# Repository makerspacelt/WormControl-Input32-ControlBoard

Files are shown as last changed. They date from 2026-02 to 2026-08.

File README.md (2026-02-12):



---
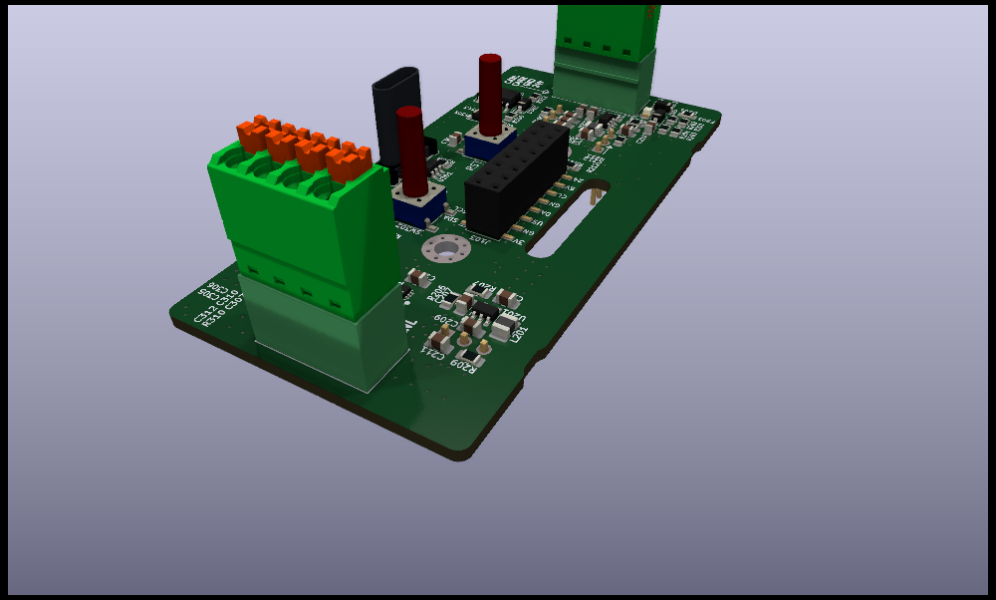
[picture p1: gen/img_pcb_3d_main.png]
PCB 3d main


WormControl Inputs Control board

NOTE: This is only a prototype now, so things might not work and everything might change 

Basic target features:

* Compatibility with esphome and Home Assistant

Dev NOTE: before commit, run `./kibot.sh` to regenerate documentation, bom, gerbers and other assets.

* [schematics.pdf](gen/schematics.pdf)
* [pcb.pdf with dimensions](gen/pcb.pdf)
* [ibom.html](gen/single/ibom.html)

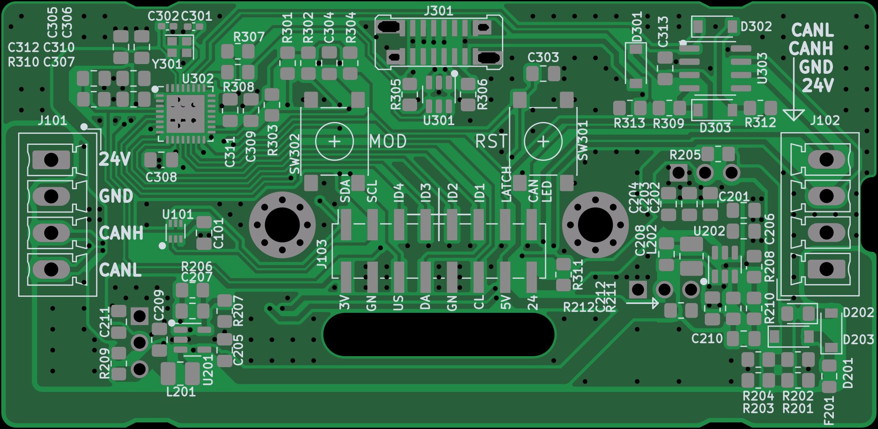
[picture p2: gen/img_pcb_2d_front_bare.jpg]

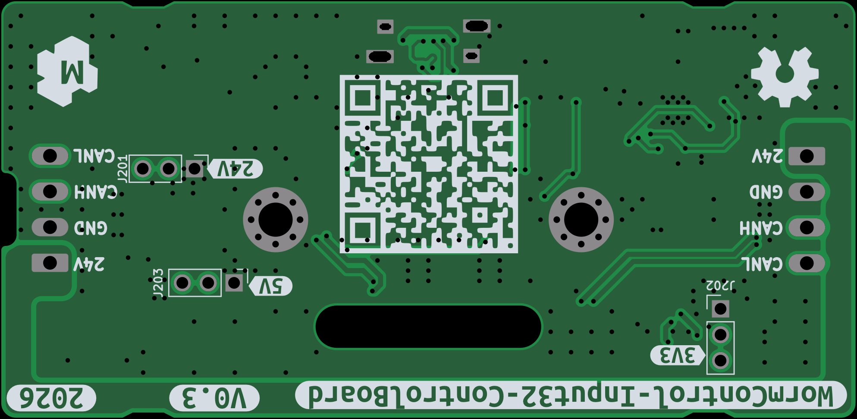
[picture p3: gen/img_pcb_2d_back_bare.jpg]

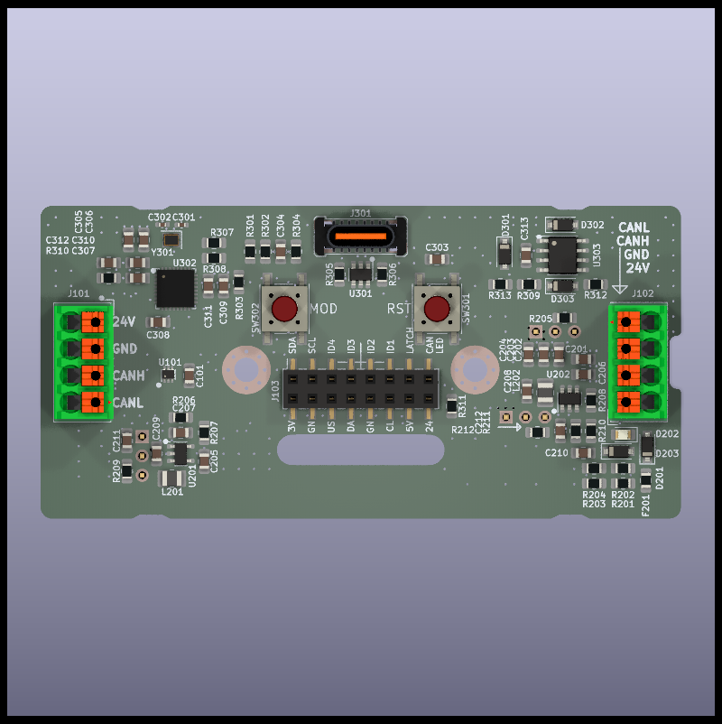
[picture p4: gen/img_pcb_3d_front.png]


---

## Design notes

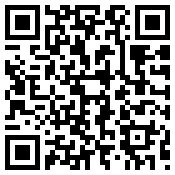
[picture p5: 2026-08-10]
gen/qr_link.png

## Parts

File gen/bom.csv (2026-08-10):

Row | Description | Part | References | Value | Footprint | Quantity Per PCB | Status | Datasheet | lcsc# | jlc-part-type
1 | Heatsink | Heatsink | BOM101,BOM102 | 1x4 screw plug |  | 2 |  | https://www.lcsc.com/datasheet/lcsc_datasheet_2309070925_DEGSON-15EDGKN-3-5-04P-14-00A-H_C7603442.pdf | C7603442 | E
2 | Unpolarized capacitor | C | C301,C302 | 10p | C_0402_1005Metric_Pad0.74x0.62mm_HandSolder | 2 |  | ~ | C32949 | B
3 | Unpolarized capacitor | C | C207,C210 | 100p | C_0805_2012Metric_Pad1.18x1.45mm_HandSolder | 2 |  | https://www.lcsc.com/datasheet/lcsc_datasheet_2304140030_Samsung-Electro-Mechanics-CL21C101JBANNNC_C1790.pdf | C1790 | B
4 | Unpolarized capacitor | C | C101,C206,C208,C303,C304,C307,C308,C309,C310,C311,C312,C313 | 100n | C_0805_2012Metric_Pad1.18x1.45mm_HandSolder | 12 |  | https://www.lcsc.com/datasheet/lcsc_datasheet_2304140030_Samsung-Electro-Mechanics-CL21B104KCFNNNE_C28233.pdf | C28233 | B
5 | Unpolarized capacitor | C | C306 | 1u | C_0805_2012Metric_Pad1.18x1.45mm_HandSolder | 1 |  | https://www.lcsc.com/datasheet/lcsc_datasheet_2304140030_Samsung-Electro-Mechanics-CL21B105KBFNNNE_C28323.pdf | C28323 | B
6 | Unpolarized capacitor | C | C201,C202,C203,C204,C212 | 10u/50v | C_0805_2012Metric_Pad1.18x1.45mm_HandSolder | 5 |  | https://www.lcsc.com/datasheet/lcsc_datasheet_2411041759_Murata-Electronics-GRM21BR61H106KE43L_C440198.pdf | C440198 | B
7 | Unpolarized capacitor | C | C205,C305 | 22u/25v | C_0805_2012Metric_Pad1.18x1.45mm_HandSolder | 2 |  | https://www.lcsc.com/datasheet/lcsc_datasheet_2304140030_Samsung-Electro-Mechanics-CL21A226MAQNNNE_C45783.pdf | C45783 | B
8 | Unpolarized capacitor | C | C209,C211 | 47u/6V3 | C_0805_2012Metric_Pad1.18x1.45mm_HandSolder | 2 |  | https://www.lcsc.com/datasheet/C16780.pdf | C16780 | B
9 | Schottky diode | D_Schottky | D201,D203,D301,D302,D303 | B5819W | D_SOD-123 | 5 |  | https://www.lcsc.com/datasheet/lcsc_datasheet_2304140030_Jiangsu-Changjing-Electronics-Technology-Co---Ltd--B5819W-SL_C8598.pdf | C8598 | B
10 | Light emitting diode | LED | D202 | BLUE | LED_0805_2012Metric_Pad1.15x1.40mm_HandSolder | 1 |  | https://www.lcsc.com/datasheet/C2297.pdf | C2297 | B
11 | Resettable fuse, polymeric positive temperature coefficient | Polyfuse | F201 | 250mA | Fuse_0805_2012Metric_Pad1.15x1.40mm_HandSolder | 1 |  | https://wmsc.lcsc.com/wmsc/upload/file/pdf/v2/lcsc/2404081622_BHFUSE-BSMD0805-025-33V_C22378353.pdf | C22378353 | E
12 | Generic connector, single row, 01x03, script generated (kicad-library-utils/schlib/autogen/connector/) | Conn_01x03 | J201,J202,J203 | 24V | PinHeader_1x03_P2.54mm_Vertical | 3 |  | ~ |  | -
13 | Generic screw terminal, single row, 01x04, script generated (kicad-library-utils/schlib/autogen/connector/) | Screw_Terminal_01x04 | J101,J102 | BUS | PhoenixContact_MCV_1,5_4-G-3.5_1x04_P3.50mm_Vertical | 2 |  | https://www.lcsc.com/datasheet/lcsc_datasheet_2304140030_Ningbo-Xinlaiya-Elec--XY2500V-F-3-5-4P_C880556.pdf | C880556 | E
14 | Generic connector, single row, 01x16, script generated (kicad-library-utils/schlib/autogen/connector/) | Conn_01x16 | J103 | Back | PinSocket_2x08_P2.54mm_Vertical_SMD | 1 |  | https://wmsc.lcsc.com/wmsc/upload/file/pdf/v2/lcsc/2306091018_HCTL-PM254-2-08-S-8-5_C3975153.pdf | C3975153 | E
15 | USB 2.0-only Type-C Receptacle connector | USB_C_Receptacle_USB2.0 | J301 | USB_C_Receptacle_USB2.0 | USB_C_Receptacle_G-Switch_GT-USB-7082G | 1 |  | https://www.lcsc.com/datasheet/lcsc_datasheet_2405271642_G-Switch-GT-USB-7082G_C22383836.pdf | C22383836 | E
16 | Inductor | L | L201,L202 | 3.3uH | L_1008_2520Metric_Pad1.43x2.20mm_HandSolder | 2 |  | https://www.lcsc.com/datasheet/C5832373.pdf | C5832373 | E
17 | Resistor | R | R205,R209,R212 | 0R1 | R_0805_2012Metric_Pad1.20x1.40mm_HandSolder | 3 |  | https://www.lcsc.com/datasheet/lcsc_datasheet_2304140030_UNI-ROYAL-Uniroyal-Elec-0805W8F100LT5E_C127687.pdf | C127687 | E
18 | Resistor | R | R307,R308 | 22R | R_0805_2012Metric_Pad1.20x1.40mm_HandSolder | 2 |  | ~ | C17561 | B
19 | Resistor | R | R309 | 1k5 | R_0805_2012Metric_Pad1.20x1.40mm_HandSolder | 1 |  | ~ | C4310 | B
20 | Resistor | R | R313 | 3k | R_0805_2012Metric_Pad1.20x1.40mm_HandSolder | 1 |  | ~ | C17661 | B
21 | Resistor | R | R201,R202,R203,R204,R301,R302,R303,R304,R305,R306,R310,R312 | 4k7 | R_0805_2012Metric_Pad1.20x1.40mm_HandSolder | 12 |  | ~ | C17673 | B
22 | Resistor | R | R207,R208,R210 | 10k | R_0805_2012Metric_Pad1.20x1.40mm_HandSolder | 3 |  | ~ | C17414 | B
23 | Resistor | R | R206 | 47k | R_0805_2012Metric_Pad1.20x1.40mm_HandSolder | 1 |  | ~ | C17713 | B
24 | Resistor | R | R211,R311 | 150k | R_0805_2012Metric_Pad1.20x1.40mm_HandSolder | 2 |  | ~ | C17470 | B
25 | Push button switch, generic, two pins | SW_Push | SW301,SW302 | 15mm | SW_SPST_15 | 2 |  | https://www.lcsc.com/datasheet/lcsc_datasheet_2110120830_XKB-Connection-TS-1102S-C-V-B_C2885154.pdf | C2885154 | E
26 | 1.2 A Simple Buck Regulator, 3-26V input, 1.5Mhz | AOZ1280CI | U202 | ME3121AM6G | SOT-23-6 | 1 |  | https://m.huazhoucn.com/upFiles/common/2022/12/ME3121_Series_E1.0.pdf | C2932938 | E
27 | 600mA Synchronous Step-Down Regulator, 1.5MHz, Adjustable Output Voltage, Burst Mode, ThinSOT-23 | LTC3406ES5 | U201 | MT3406 | TSOT-23-5 | 1 |  | https://www.lcsc.com/datasheet/lcsc_datasheet_2406131737_XI-AN-Aerosemi-Tech-MT3406_C22462728.pdf | C22462728 | E
28 | Digital Temperature Sensor, +/- 3 °C, low-Power, SMBus, 12 bit, Two-Wire Serial Interface, SOT-563 | TMP102xxDRL | U101 | TMP102 | SOT-563 | 1 |  | https://www.ti.com/lit/ds/symlink/tmp102.pdf | C99269 | E
29 | Very low capacitance ESD protection diode, 2 data-line, SOT-23-6 | USBLC6-2SC6 | U301 | USBLC6-2SC6 | SOT-23-6 | 1 |  | https://www.lcsc.com/datasheet/lcsc_datasheet_2311091738_UMW-Youtai-Semiconductor-Co---Ltd--USBLC6-2SC6_C2687116.pdf | C2687116 | E
30 | High-Speed CAN Transceiver, standby mode, split pin, SOIC-8 | TJA1042T | U303 | XL1050 | SOIC-8_3.9x4.9mm_P1.27mm | 1 |  | https://www.lcsc.com/datasheet/lcsc_datasheet_2309141025_XINLUDA-XL1050_C609746.pdf | C609746 | E
31 | esp32-C3FH4X 4MB flash QFN32-1EP 5x5mm EP3.7x3.7mm | esp32-C3FH4X | U302 | esp32-C3FH4X | QFN-32-1EP_5x5mm_P0.5mm_EP3.65x3.65mm | 1 |  | https://www.espressif.com/sites/default/files/documentation/esp32-c3_datasheet_en.pdf | C2858491 | E
32 | Four pin crystal, GND on pins 2 and 4 | Crystal_GND24 | Y301 | 40MHz | Crystal_SMD_2016-4Pin_2.0x1.6mm | 1 |  | https://www.lcsc.com/datasheet/C20885029.pdf | C20885029 | E

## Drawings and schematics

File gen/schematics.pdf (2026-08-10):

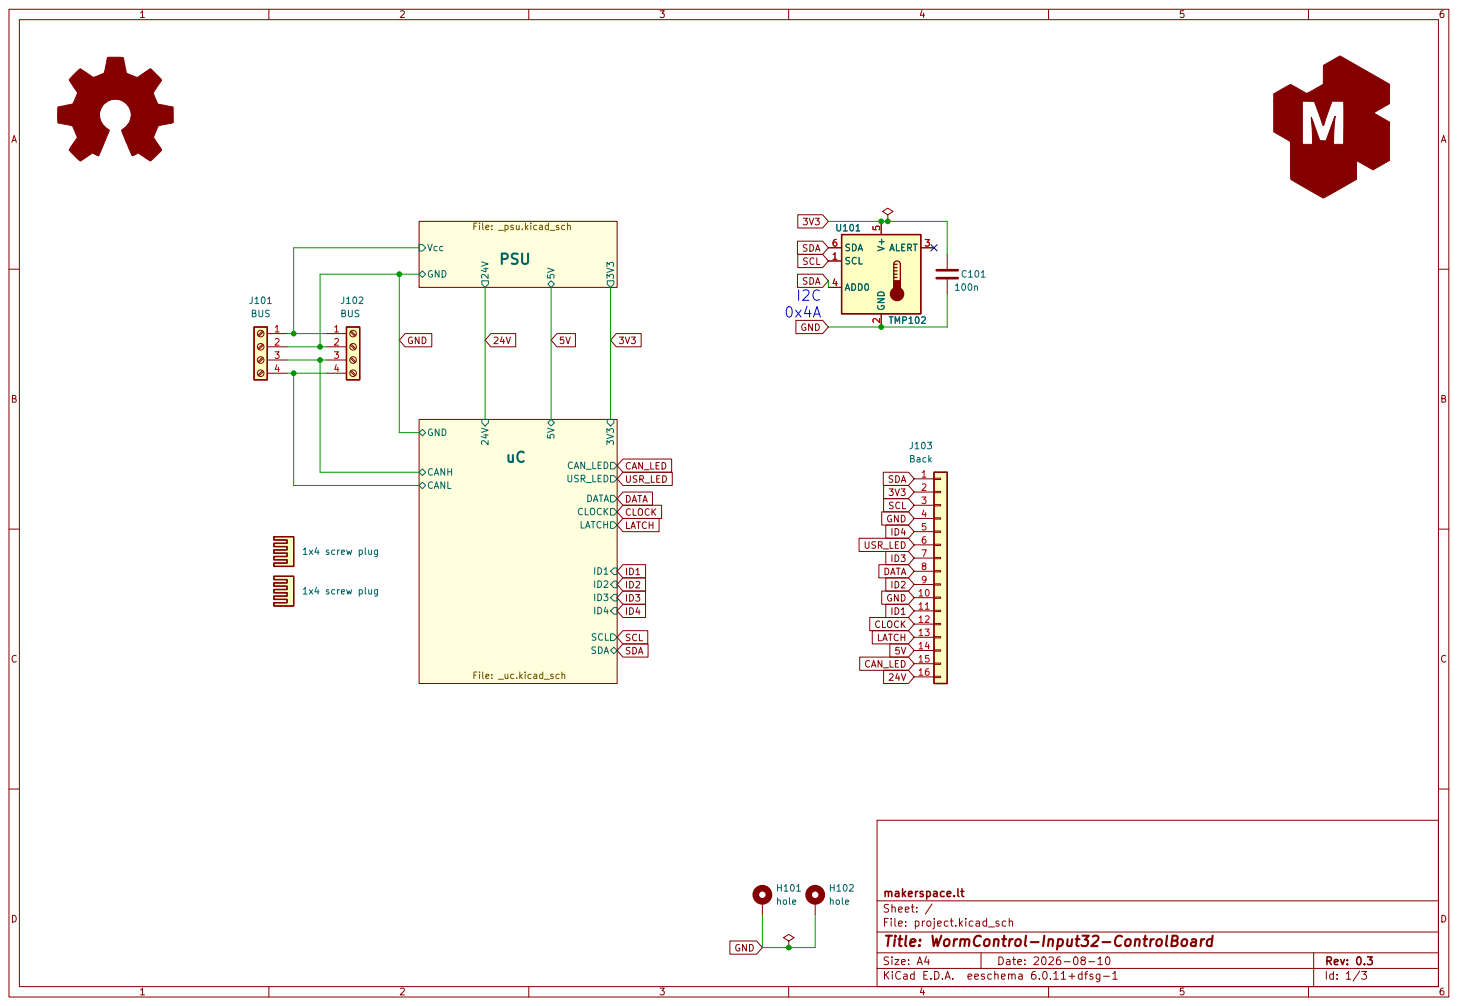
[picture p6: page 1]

Id: 1/3 Title: WormControl-Input32-ControlBoard

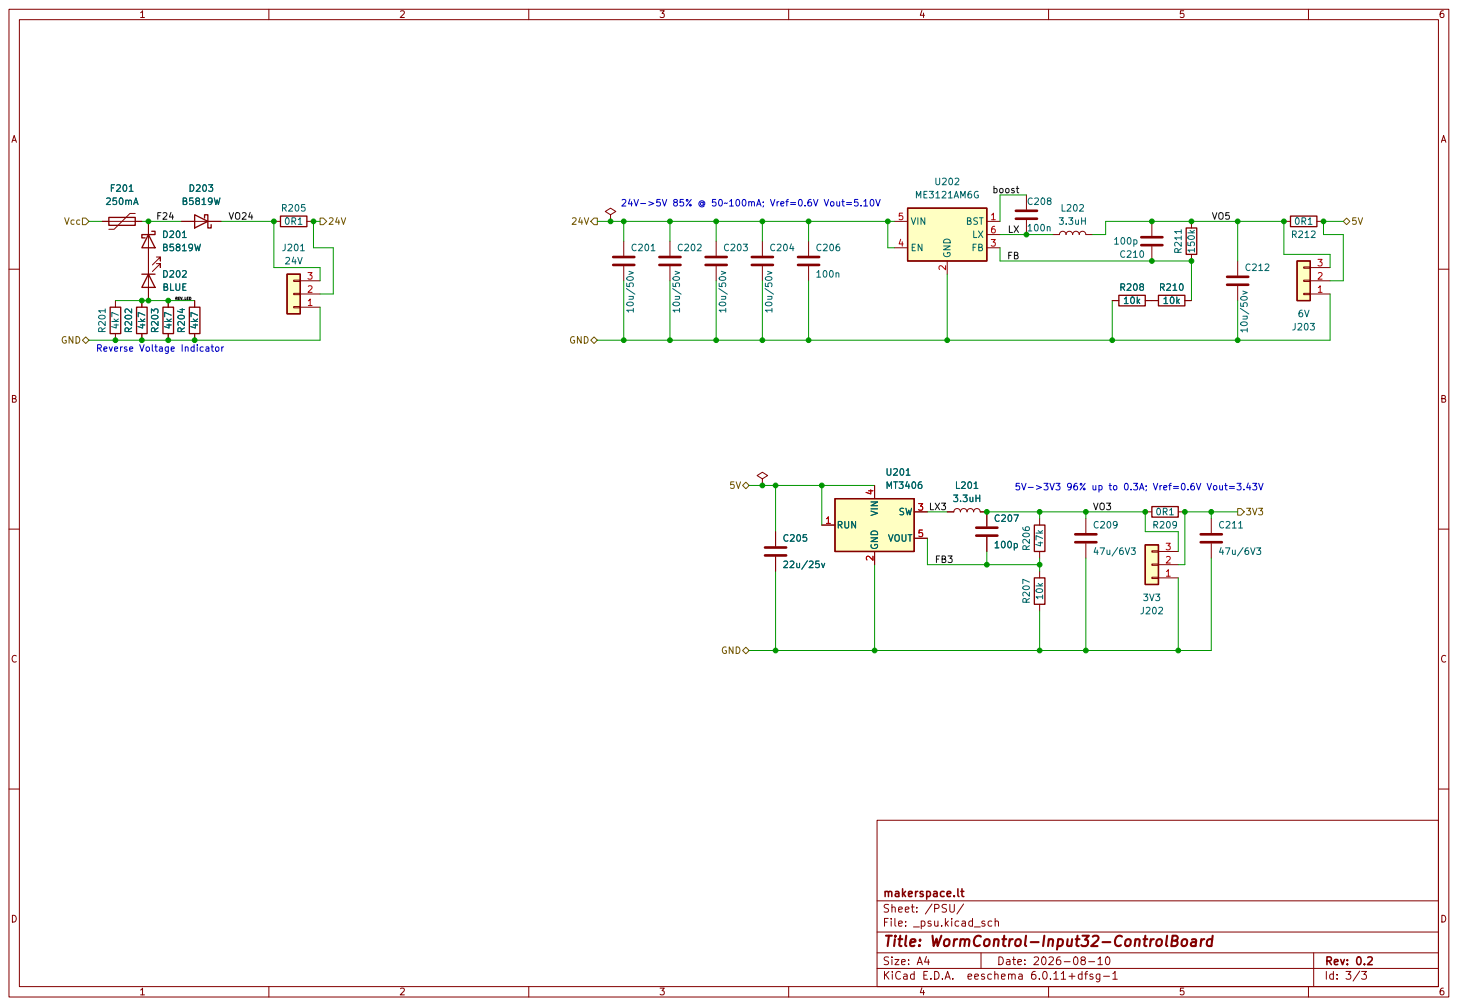
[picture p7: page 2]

File: _psu.kicad_sch Sheet: /PSU/ makerspace.lt

Id: 3/3 Title: WormControl-Input32-ControlBoard

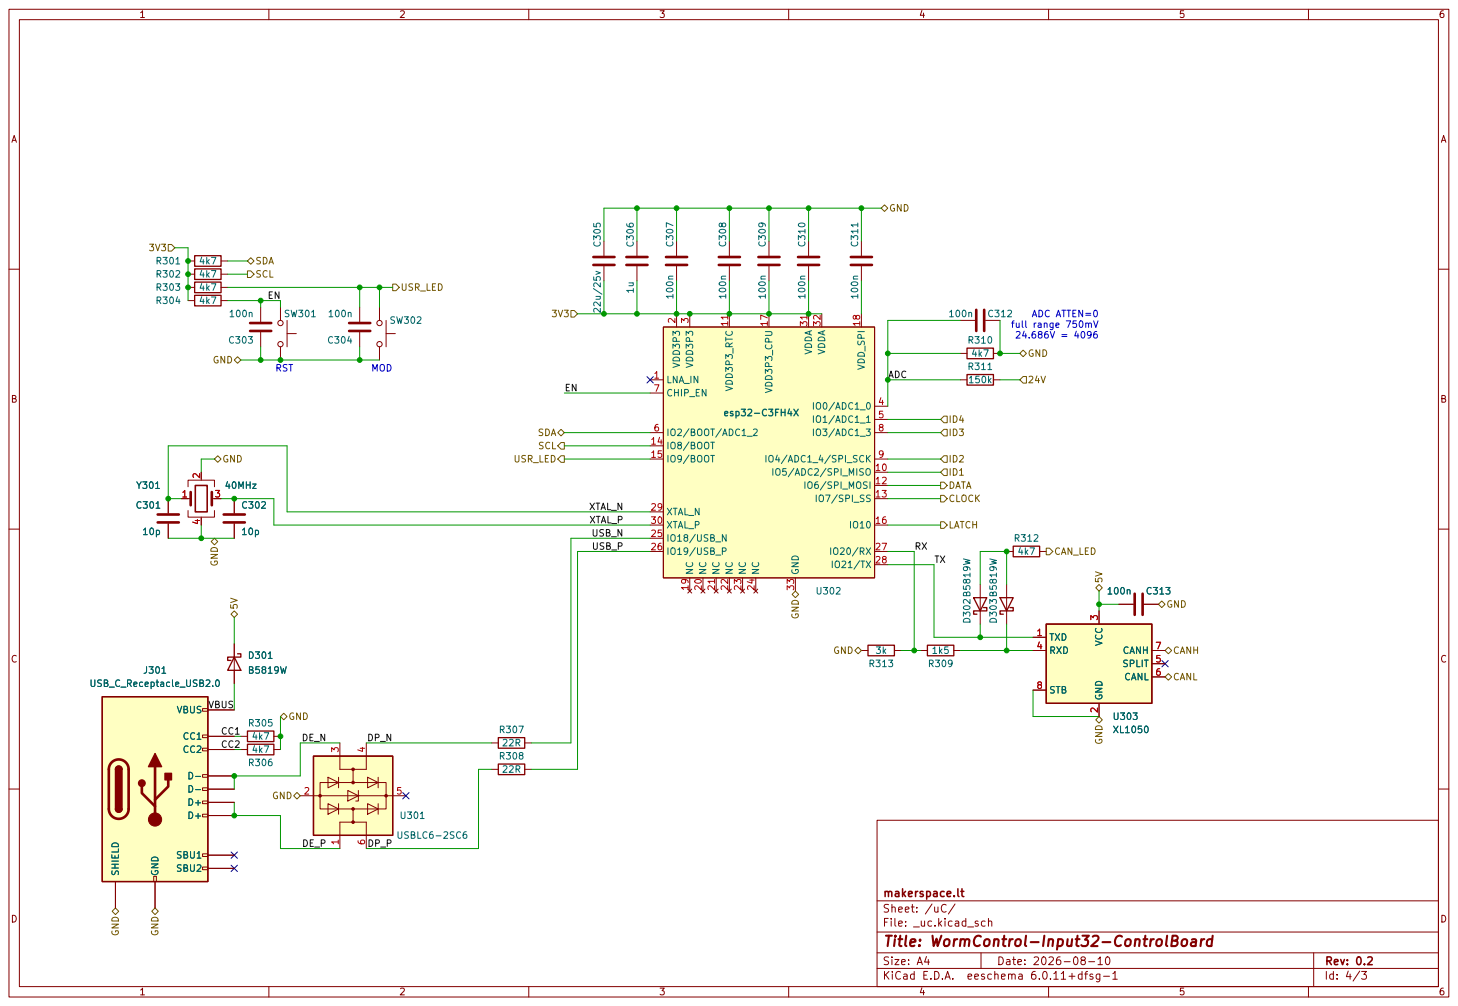
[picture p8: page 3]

Id: 4/3 Title: WormControl-Input32-ControlBoard

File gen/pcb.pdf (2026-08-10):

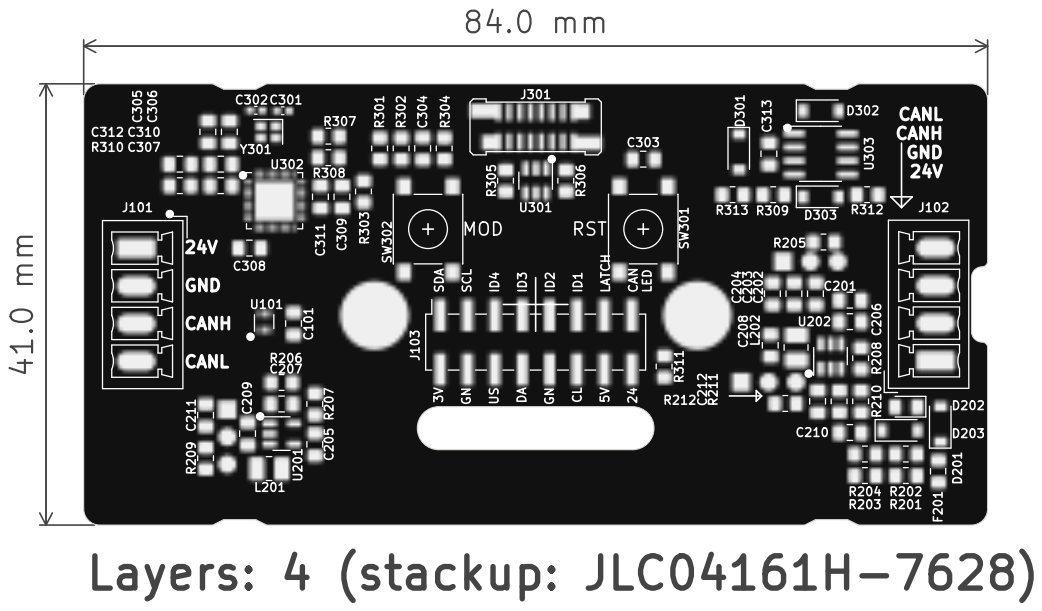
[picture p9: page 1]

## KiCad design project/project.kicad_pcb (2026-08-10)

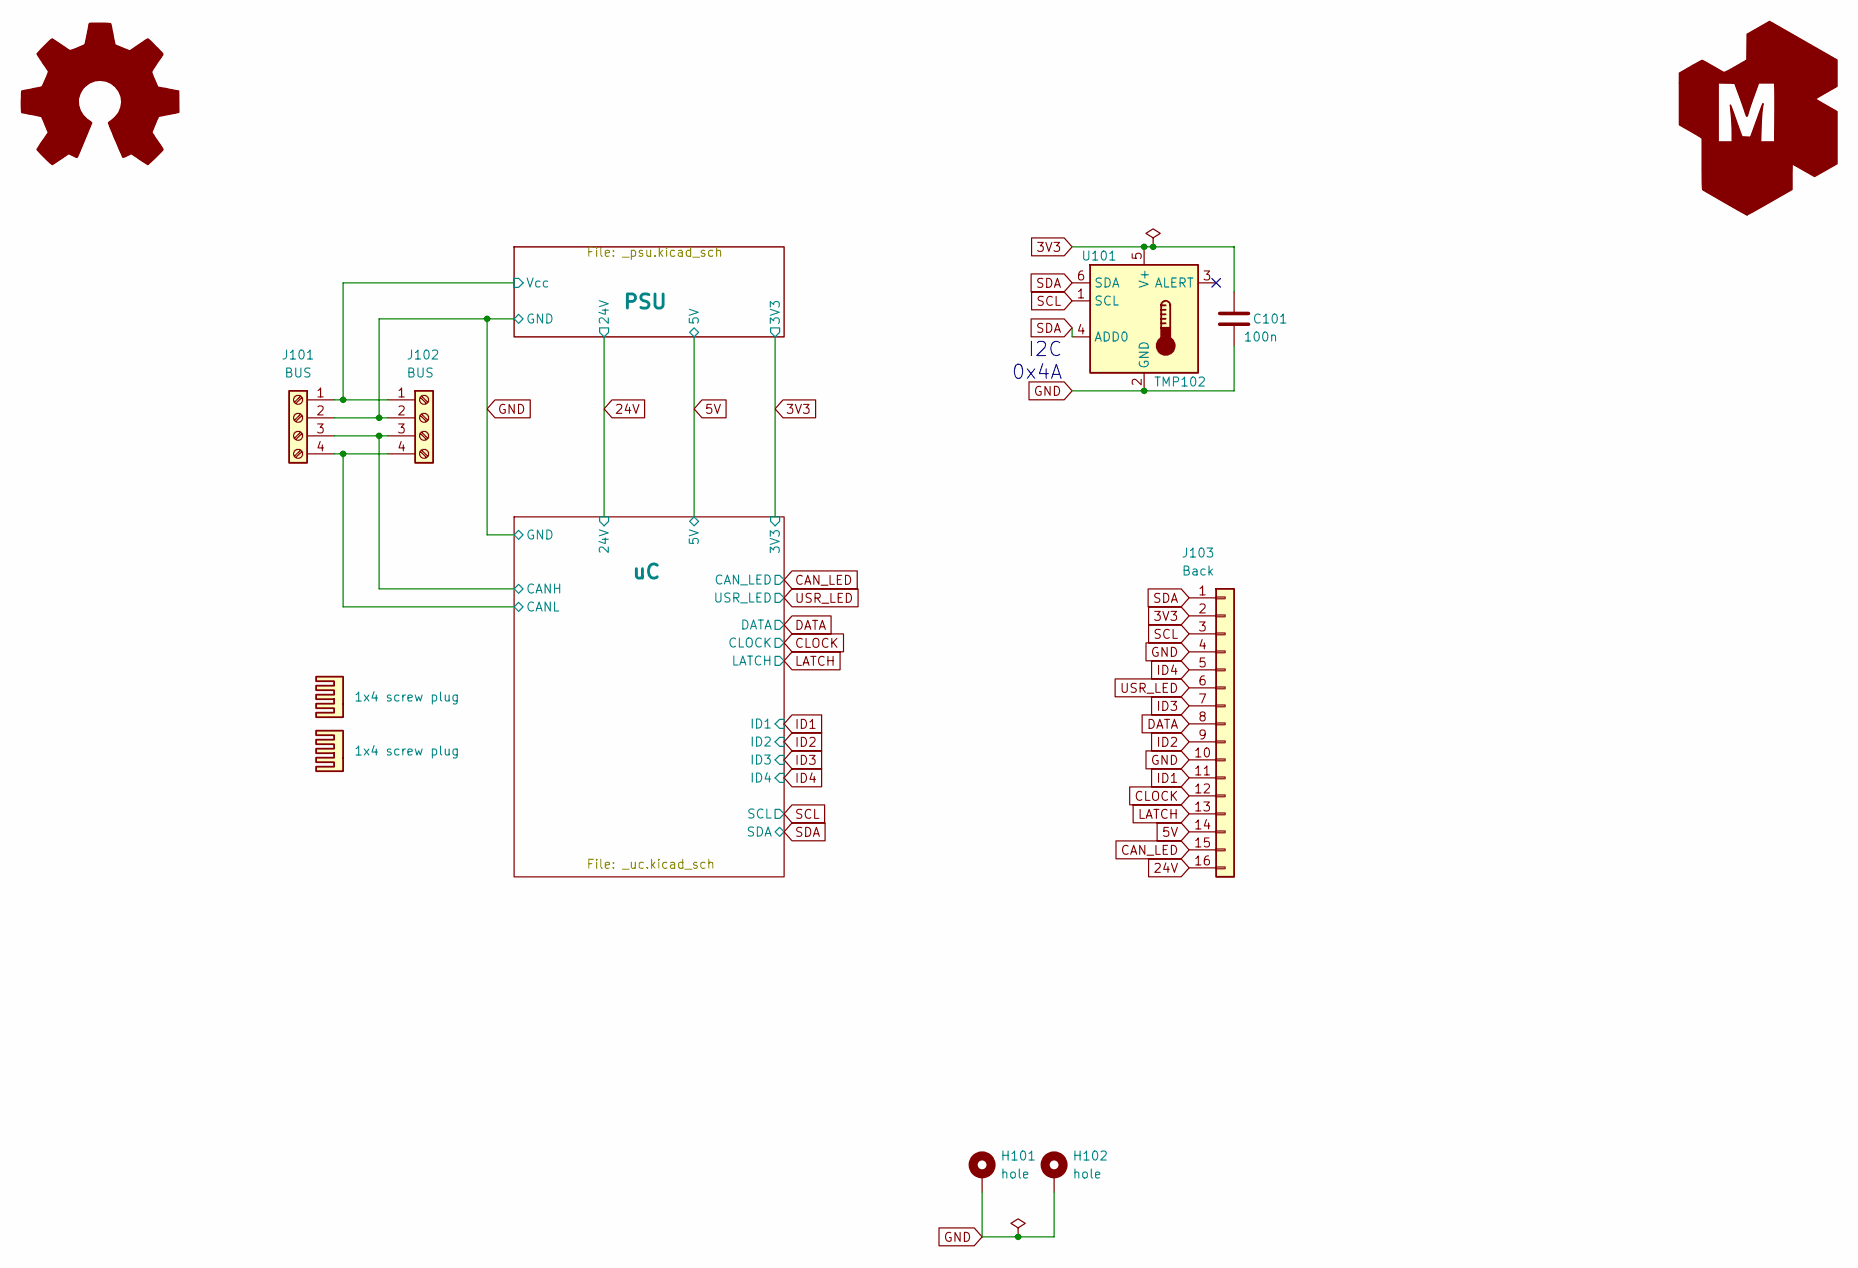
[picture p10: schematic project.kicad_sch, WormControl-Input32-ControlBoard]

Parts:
BOM101, BOM102: 1x4 screw plug; jlc-part-type E
C101: 100n; C_0805_2012Metric_Pad1.18x1.45mm_HandSolder; jlc-part-type B
G101: Logo_Open_Hardware_Large; OSHW-Symbol_6.7x6mm_SilkScreen
G102: LOGO_KMS; logo_kms_small_silkscreen
H101, H102: hole; MountingHole_3.2mm_M3_Pad_Via
J101, J102: BUS; PhoenixContact_MCV_1,5_4-G-3.5_1x04_P3.50mm_Vertical; jlc-part-type E
J103: Back; PinSocket_2x08_P2.54mm_Vertical_SMD; lcsc# C3975153
U101: TMP102; SOT-563; jlc-part-type E

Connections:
3V3: C101.1, J103.2, U101.5 (V+); also elsewhere on the board
5V: J103.14; also elsewhere on the board
24V: J103.16; also elsewhere on the board
/PSU/Vcc: J101.1, J102.1; also elsewhere on the board
/uC/CANH: J101.3, J102.3; also elsewhere on the board
/uC/CANL: J101.4, J102.4; also elsewhere on the board
CAN_LED: J103.15; also elsewhere on the board
CLOCK: J103.12; also elsewhere on the board
DATA: J103.8; also elsewhere on the board
GND: C101.2, H101.1, H102.1, J101.2, J102.2, J103.4, J103.10, U101.2 (GND); also elsewhere on the board
ID1: J103.11; also elsewhere on the board
ID2: J103.9; also elsewhere on the board
ID3: J103.7; also elsewhere on the board
ID4: J103.5; also elsewhere on the board
LATCH: J103.13; also elsewhere on the board
SCL: J103.3, U101.1 (SCL); also elsewhere on the board
SDA: J103.1, U101.4 (ADD0), U101.6 (SDA); also elsewhere on the board
USR_LED: J103.6; also elsewhere on the board

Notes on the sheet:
I2C 0x4A

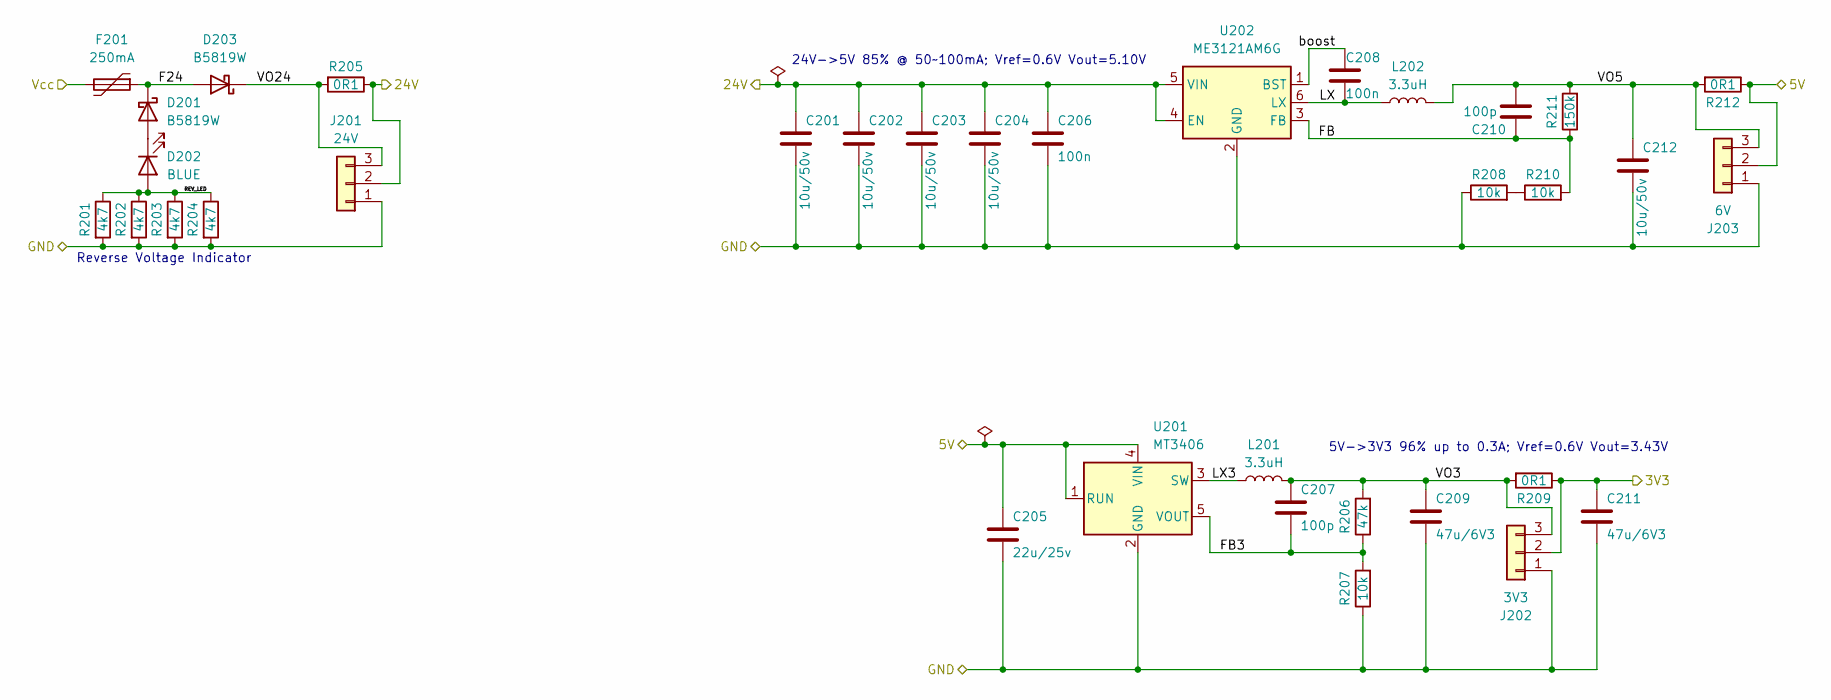
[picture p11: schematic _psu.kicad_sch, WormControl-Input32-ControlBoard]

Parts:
C201, C202, C203, C204, C212: 10u/50v; C_0805_2012Metric_Pad1.18x1.45mm_HandSolder; jlc-part-type B
C205: 22u/25v; C_0805_2012Metric_Pad1.18x1.45mm_HandSolder; jlc-part-type B
C206, C208: 100n; C_0805_2012Metric_Pad1.18x1.45mm_HandSolder; jlc-part-type B
C207, C210: 100p; C_0805_2012Metric_Pad1.18x1.45mm_HandSolder; jlc-part-type B
C209, C211: 47u/6V3; C_0805_2012Metric_Pad1.18x1.45mm_HandSolder; jlc-part-type B
D201, D203: B5819W; D_SOD-123; jlc-part-type B
D202: BLUE; LED_0805_2012Metric_Pad1.15x1.40mm_HandSolder; jlc-part-type B
F201: 250mA; Fuse_0805_2012Metric_Pad1.15x1.40mm_HandSolder; lcsc# C22378353
J201: 24V; PinHeader_1x03_P2.54mm_Vertical
J202: 3V3; PinHeader_1x03_P2.54mm_Vertical
J203: 6V; PinHeader_1x03_P2.54mm_Vertical
L201, L202: 3.3uH; L_1008_2520Metric_Pad1.43x2.20mm_HandSolder; jlc-part-type E
R201, R202, R203, R204: 4k7; R_0805_2012Metric_Pad1.20x1.40mm_HandSolder; jlc-part-type B
R205, R209, R212: 0R1; R_0805_2012Metric_Pad1.20x1.40mm_HandSolder; jlc-part-type E
R206: 47k; R_0805_2012Metric_Pad1.20x1.40mm_HandSolder; jlc-part-type B
R207, R208, R210: 10k; R_0805_2012Metric_Pad1.20x1.40mm_HandSolder; jlc-part-type B
R211: 150k; R_0805_2012Metric_Pad1.20x1.40mm_HandSolder; jlc-part-type B
U201: MT3406; TSOT-23-5; jlc-part-type E
U202: ME3121AM6G; SOT-23-6; jlc-part-type E

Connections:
3V3: C211.1, J202.2, R209.1; also elsewhere on the board
5V: C205.1, J203.2, R212.1, U201.1 (RUN), U201.4 (VIN); also elsewhere on the board
24V: C201.1, C202.1, C203.1, C204.1, C206.1, J201.2, R205.1, U202.4 (EN), U202.5 (VIN); also elsewhere on the board
/PSU/F24: D201.1 (K), D203.2 (A), F201.1
/PSU/FB: C210.1, R210.2, R211.1, U202.3 (FB)
/PSU/FB3: C207.2, R206.1, R207.2, U201.5 (VOUT)
/PSU/LX: C208.2, L202.1, U202.6 (LX)
/PSU/LX3: L201.1, U201.3 (SW)
/PSU/REV_LED: D202.2 (A), R201.1, R202.1, R203.1, R204.1
/PSU/VO3: C207.1, C209.1, J202.3, L201.2, R206.2, R209.2
/PSU/VO5: C210.2, C212.1, J203.3, L202.2, R211.2, R212.2
/PSU/VO24: D203.1 (K), J201.3, R205.2
/PSU/Vcc: F201.2; also elsewhere on the board
/PSU/boost: C208.1, U202.1 (BST)
GND: C201.2, C202.2, C203.2, C204.2, C205.2, C206.2, C209.2, C211.2, C212.2, J201.1, J202.1, J203.1, R201.2, R202.2, R203.2, R204.2, R207.1, R208.1, U201.2 (GND), U202.2 (GND); also elsewhere on the board
unnamed: D201.2 (A), D202.1 (K)
unnamed: R208.2, R210.1

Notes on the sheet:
24V->5V 85% @ 50~100mA; Vref=0.6V Vout=5.10V
5V->3V3 96% up to 0.3A; Vref=0.6V Vout=3.43V
Reverse Voltage Indicator

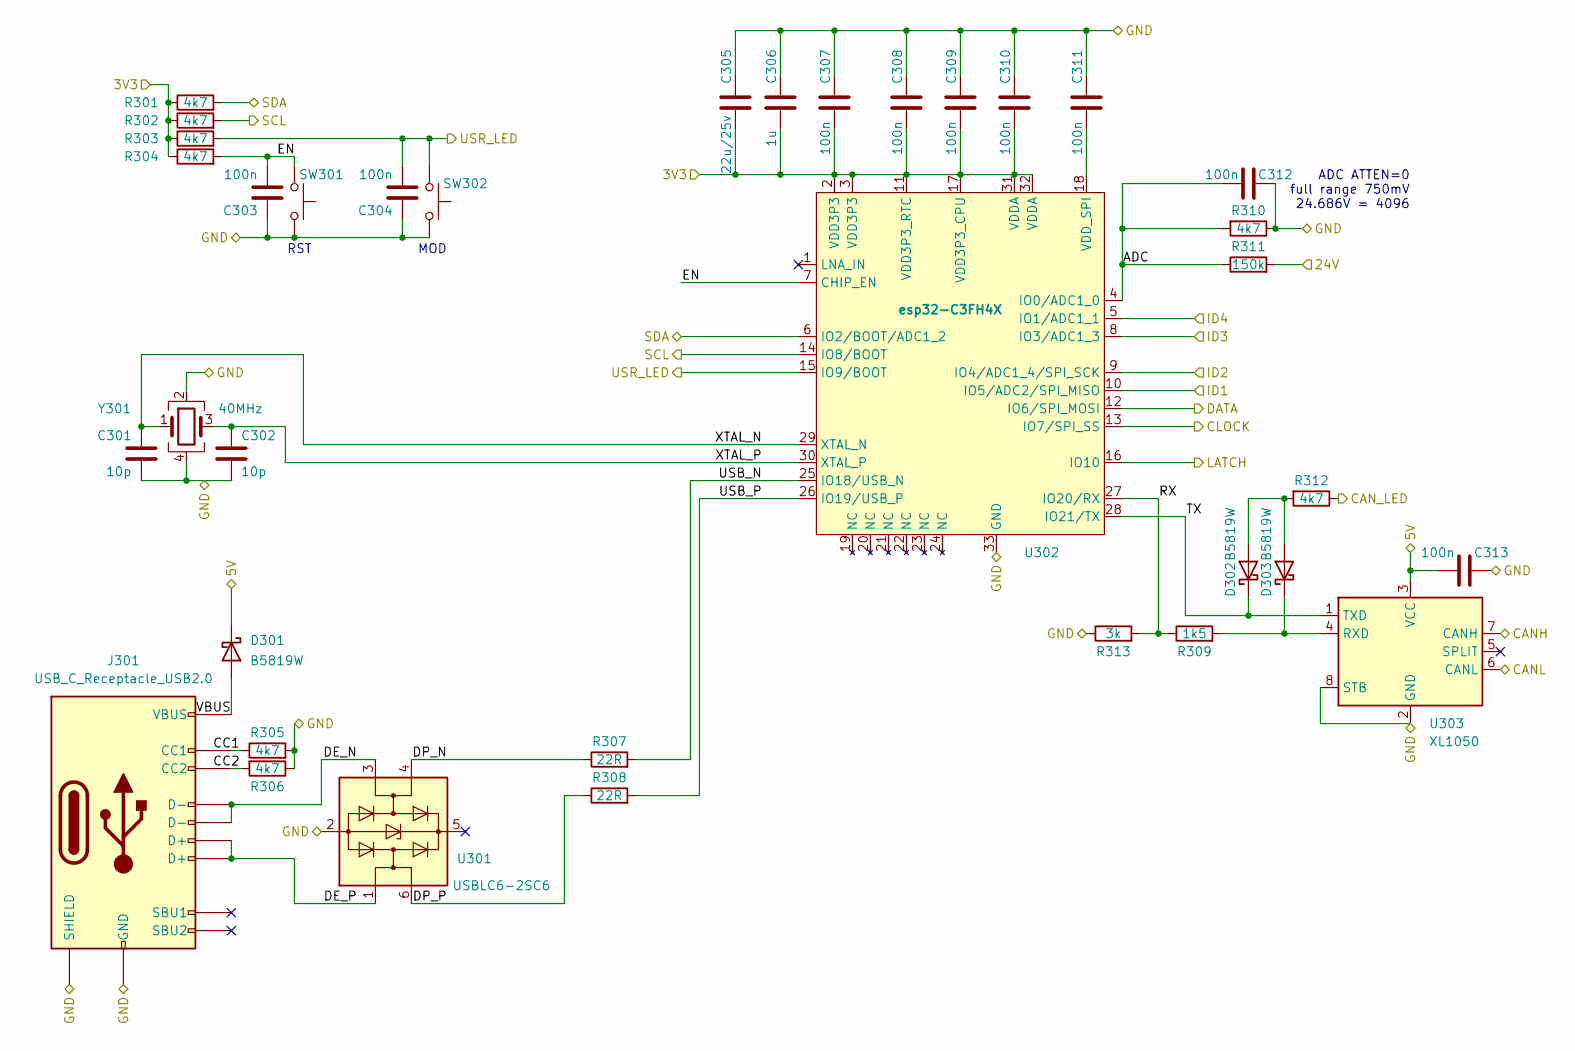
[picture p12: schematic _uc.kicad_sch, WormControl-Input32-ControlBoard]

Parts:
C301, C302: 10p; C_0402_1005Metric_Pad0.74x0.62mm_HandSolder; jlc-part-type B
C303, C304, C307, C308, C309, C310, C311, C312, C313: 100n; C_0805_2012Metric_Pad1.18x1.45mm_HandSolder; jlc-part-type B
C305: 22u/25v; C_0805_2012Metric_Pad1.18x1.45mm_HandSolder; jlc-part-type B
C306: 1u; C_0805_2012Metric_Pad1.18x1.45mm_HandSolder; jlc-part-type B
D301, D302, D303: B5819W; D_SOD-123; jlc-part-type B
J301: USB_C_Receptacle_USB2.0; USB_C_Receptacle_G-Switch_GT-USB-7082G; jlc-part-type E
R301, R302, R303, R304, R305, R306, R310, R312: 4k7; R_0805_2012Metric_Pad1.20x1.40mm_HandSolder; jlc-part-type B
R307, R308: 22R; R_0805_2012Metric_Pad1.20x1.40mm_HandSolder; jlc-part-type B
R309: 1k5; R_0805_2012Metric_Pad1.20x1.40mm_HandSolder; jlc-part-type B
R311: 150k; R_0805_2012Metric_Pad1.20x1.40mm_HandSolder; jlc-part-type B
R313: 3k; R_0805_2012Metric_Pad1.20x1.40mm_HandSolder; jlc-part-type B
SW301, SW302: 15mm; SW_SPST_15; jlc-part-type E
U301: USBLC6-2SC6; SOT-23-6; jlc-part-type E
U302: esp32-C3FH4X; QFN-32-1EP_5x5mm_P0.5mm_EP3.65x3.65mm; jlc-part-type E
U303: XL1050; SOIC-8_3.9x4.9mm_P1.27mm; jlc-part-type E
Y301: 40MHz; Crystal_SMD_2016-4Pin_2.0x1.6mm; jlc-part-type E

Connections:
3V3: C305.2, C306.2, C307.1, C308.1, C309.1, C310.1, R301.1, R302.1, R303.1, R304.1, U302.2 (VDD3P3), U302.3 (VDD3P3), U302.11 (VDD3P3_RTC), U302.17 (VDD3P3_CPU), U302.31 (VDDA), U302.32 (VDDA); also elsewhere on the board
5V: C313.1, D301.1 (K), U303.3 (VCC); also elsewhere on the board
24V: R311.2; also elsewhere on the board
/uC/ADC: C312.1, R310.2, R311.1, U302.4 (IO0/ADC1_0)
/uC/CANH: U303.7 (CANH); also elsewhere on the board
/uC/CANL: U303.6 (CANL); also elsewhere on the board
/uC/CC1: J301.A5 (CC1), R305.1
/uC/CC2: J301.B5 (CC2), R306.2
/uC/DE_N: J301.A7 (D-), J301.B7 (D-), U301.3 (I/O2)
/uC/DE_P: J301.A6 (D+), J301.B6 (D+), U301.1 (I/O1)
/uC/DP_N: R307.1, U301.4 (I/O2)
/uC/DP_P: R308.1, U301.6 (I/O1)
/uC/EN: C303.2, R304.2, SW301.1, U302.7 (CHIP_EN)
/uC/RX: R309.1, R313.2, U302.27 (IO20/RX)
/uC/TX: D302.1 (K), U302.28 (IO21/TX), U303.1 (TXD)
/uC/USB_N: R307.2, U302.25 (IO18/USB_N)
/uC/USB_P: R308.2, U302.26 (IO19/USB_P)
/uC/VBUS: D301.2 (A), J301.A4 (VBUS), J301.A9 (VBUS), J301.B4 (VBUS), J301.B9 (VBUS)
/uC/XTAL_N: C301.1, U302.29 (XTAL_N), Y301.1
/uC/XTAL_P: C302.1, U302.30 (XTAL_P), Y301.3
CAN_LED: R312.1; also elsewhere on the board
CLOCK: U302.13 (IO7/SPI_SS); also elsewhere on the board
DATA: U302.12 (IO6/SPI_MOSI); also elsewhere on the board
GND: C301.2, C302.2, C303.1, C304.1, C305.1, C306.1, C307.2, C308.2, C309.2, C310.2, C311.2, C312.2, C313.2, J301.A1 (GND), J301.A12 (GND), J301.B1 (GND), J301.B12 (GND), J301.S1 (SHIELD), R305.2, R306.1, R310.1, R313.1, SW301.2, SW302.2, U301.2 (GND), U302.33 (GND), U303.2 (GND), U303.8 (STB), Y301.2, Y301.4; also elsewhere on the board
ID1: U302.10 (IO5/ADC2/SPI_MISO); also elsewhere on the board
ID2: U302.9 (IO4/ADC1_4/SPI_SCK); also elsewhere on the board
ID3: U302.8 (IO3/ADC1_3); also elsewhere on the board
ID4: U302.5 (IO1/ADC1_1); also elsewhere on the board
LATCH: U302.16 (IO10); also elsewhere on the board
unnamed: C311.1, U302.18 (VDD_SPI)
unnamed: D302.2 (A), D303.2 (A), R312.2
unnamed: D303.1 (K), R309.2, U303.4 (RXD)
SCL: R302.2, U302.14 (IO8/BOOT); also elsewhere on the board
SDA: R301.2, U302.6 (IO2/BOOT/ADC1_2); also elsewhere on the board
USR_LED: C304.2, R303.2, SW302.1, U302.15 (IO9/BOOT); also elsewhere on the board

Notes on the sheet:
RST
ADC ATTEN=0 full range 750mV 24.686V = 4096
MOD

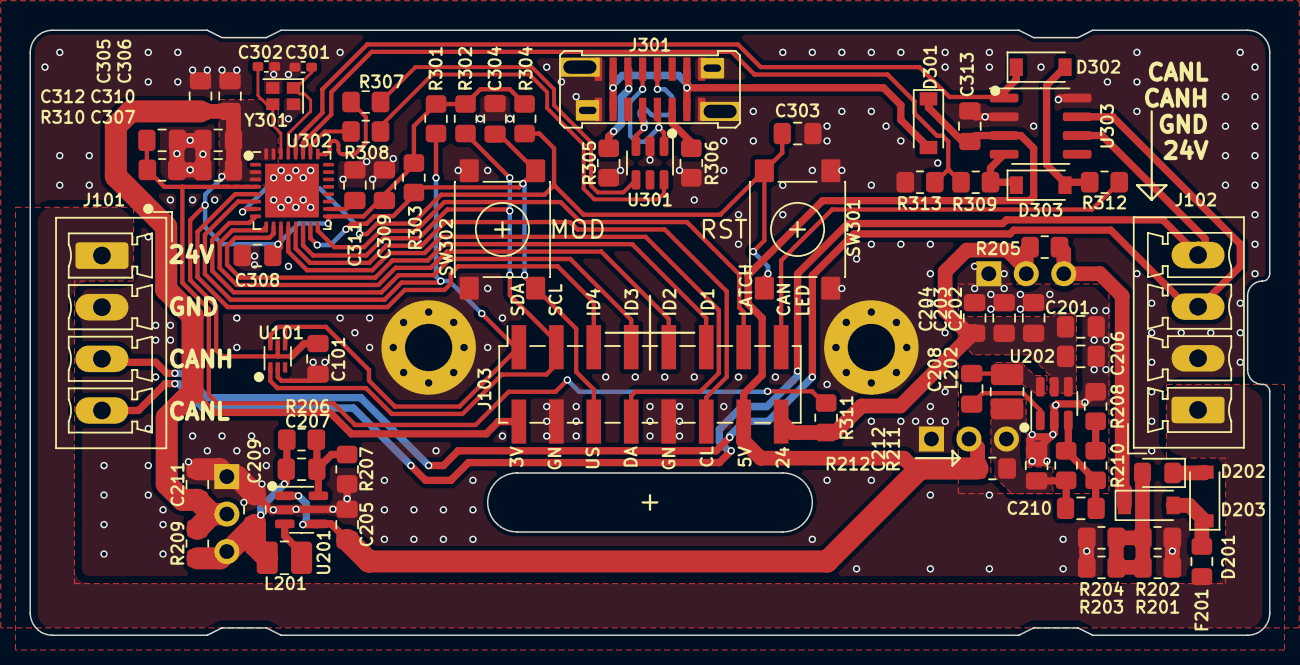
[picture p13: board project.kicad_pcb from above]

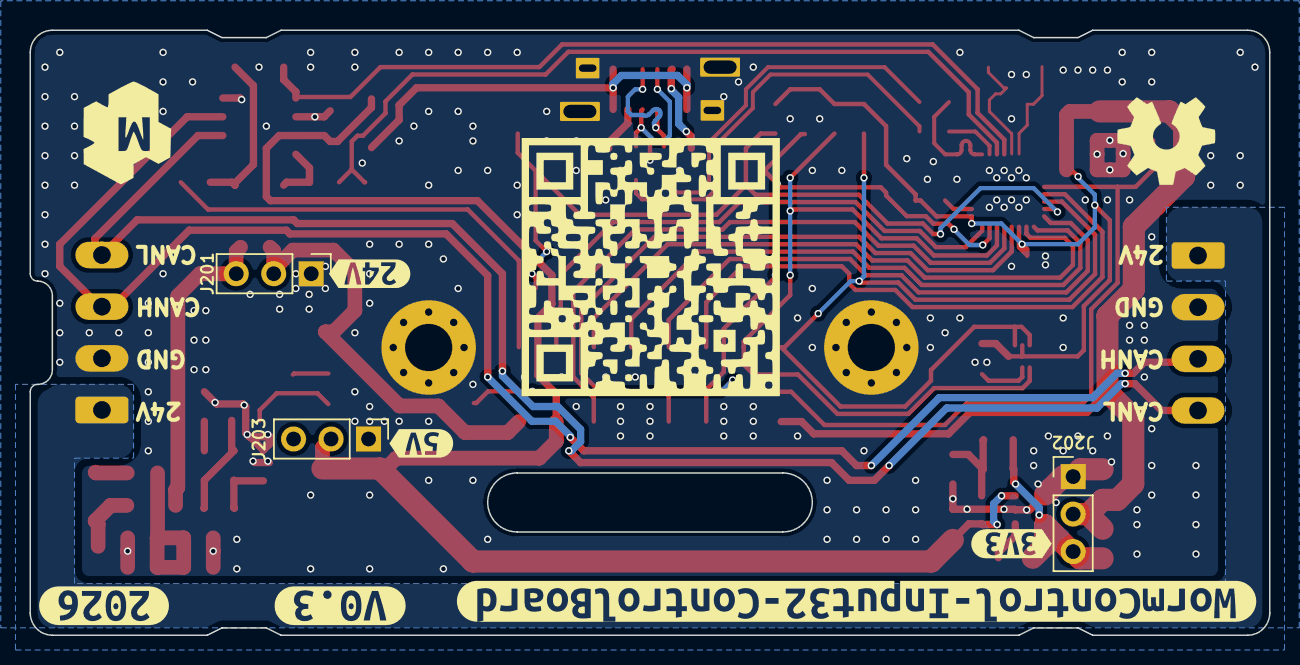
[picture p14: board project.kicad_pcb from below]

Board: 4 copper layers, 84.0 x 41.0 mm, 86 parts (11 on the bottom side), 48 nets.

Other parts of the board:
kibuzzard-6A7A000F: G***; kibuzzard-6A7A000F
kibuzzard-68F6C776: G***; kibuzzard-68F6C776
kibuzzard-69BC7F29: G***; kibuzzard-69BC7F29
kibuzzard-698AF99F: G***; kibuzzard-698AF99F
kibuzzard-698C575A: G***; kibuzzard-698C575A
kibuzzard-698C579F: G***; kibuzzard-698C579F

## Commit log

2026-02-12 initial prototype
    [_psu.kicad_sch, _uc.kicad_sch, project.kicad_pcb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]
2026-02-12 updating kibot and generatables
    [_bom.csv, bom.csv, bom_lcsc.csv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]
2026-03-19 fixes after preliminary testing
    * Switching to TMP102 as TMP101 is no longer available
    * Removing 5V LDO with OVP as it caused more problems
    * bumping up version
    [_bom.csv, _psu.kicad_sch, _uc.kicad_sch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]
2026-04-20 fixing tmp102 pinout
    [bom.csv, project.kicad_pcb, project.kicad_sch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]
2026-08-10 fixing CAN level shifting resistors
    [_bom.csv, _psu.kicad_sch, _uc.kicad_sch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]
